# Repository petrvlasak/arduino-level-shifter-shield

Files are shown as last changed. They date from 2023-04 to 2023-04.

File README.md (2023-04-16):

# Arduino Logic Level Shifter Shield

This shield is used to convert the logic 1 (HIGH) voltage at the Arduino digital pins so that logic circuits that use a different logic 1 (HIGH) voltage can be connected to it. The Shield can be used with the Arduino UNO board and any other board that has the same layout and pinout as this board. The pins are divided into three groups of eight. It is possible to choose a different voltage for each of these three groups. In the third group, only four pins are connected to the Arduino. The remaining four pins S0 - S3 are of general use and convert the IOREF voltage to the voltage set for the third group. The voltage is changed by a switch that has three options:

1. Voltage 3.3 V from Arduino
2. The voltage set by the potentiometer on the regulator varies between approximately 1.5 V - 2.8 V (the input for the regulator can be pin +5V or pin Vin)
3. External voltage - The allowed range of this voltage is 1.4V - 3.6V

## Schematic

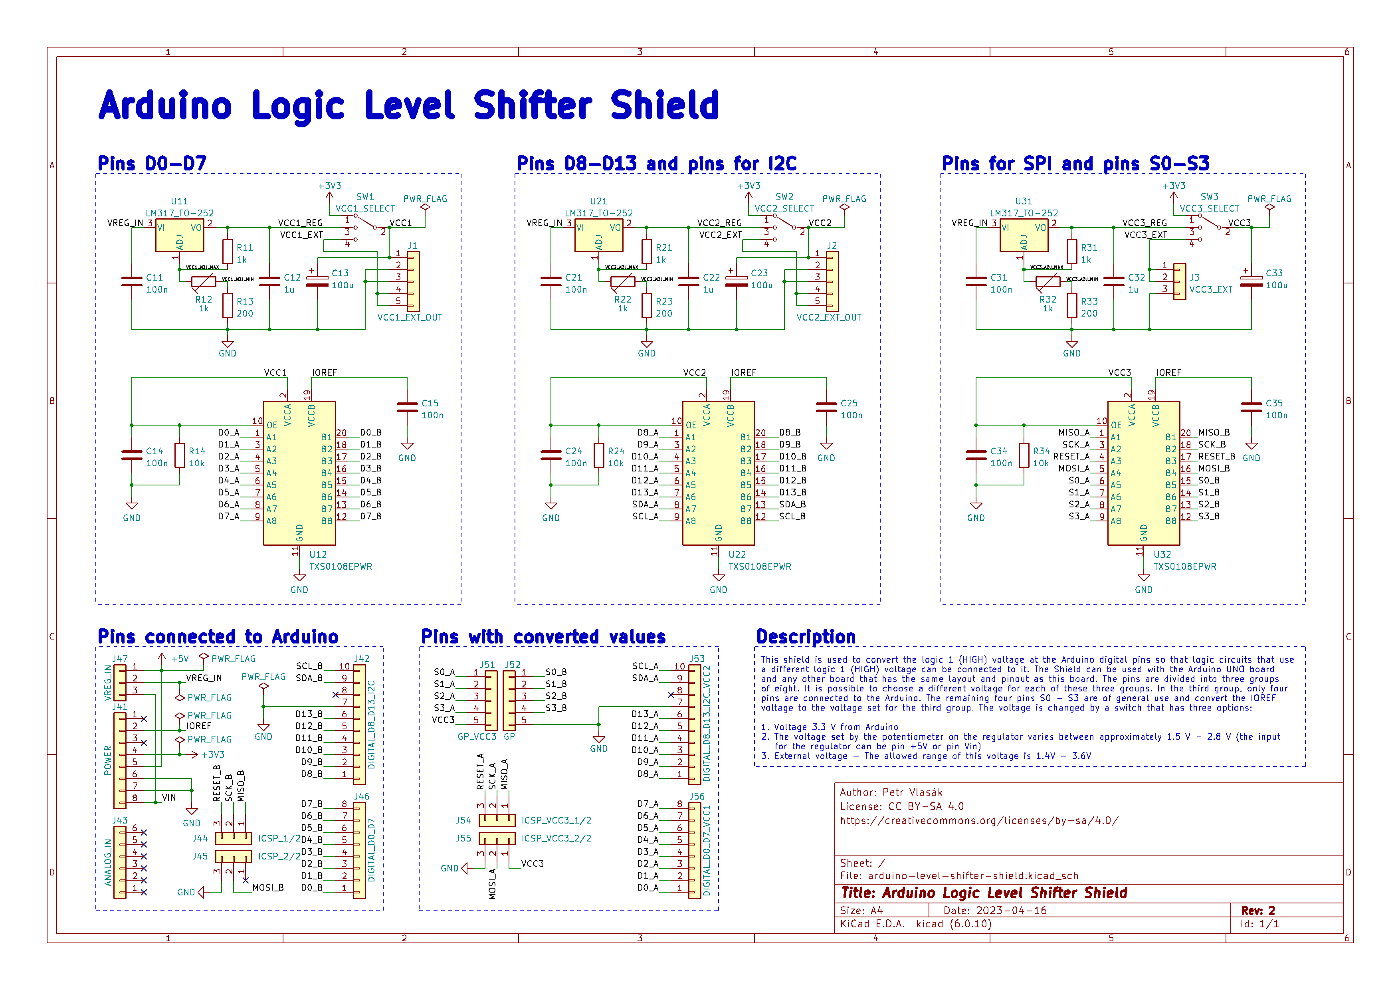
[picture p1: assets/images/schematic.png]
Schematic


## Manufacturing

The PCB manufacturing files are located [here](/manufacturing/).

## Placement plan

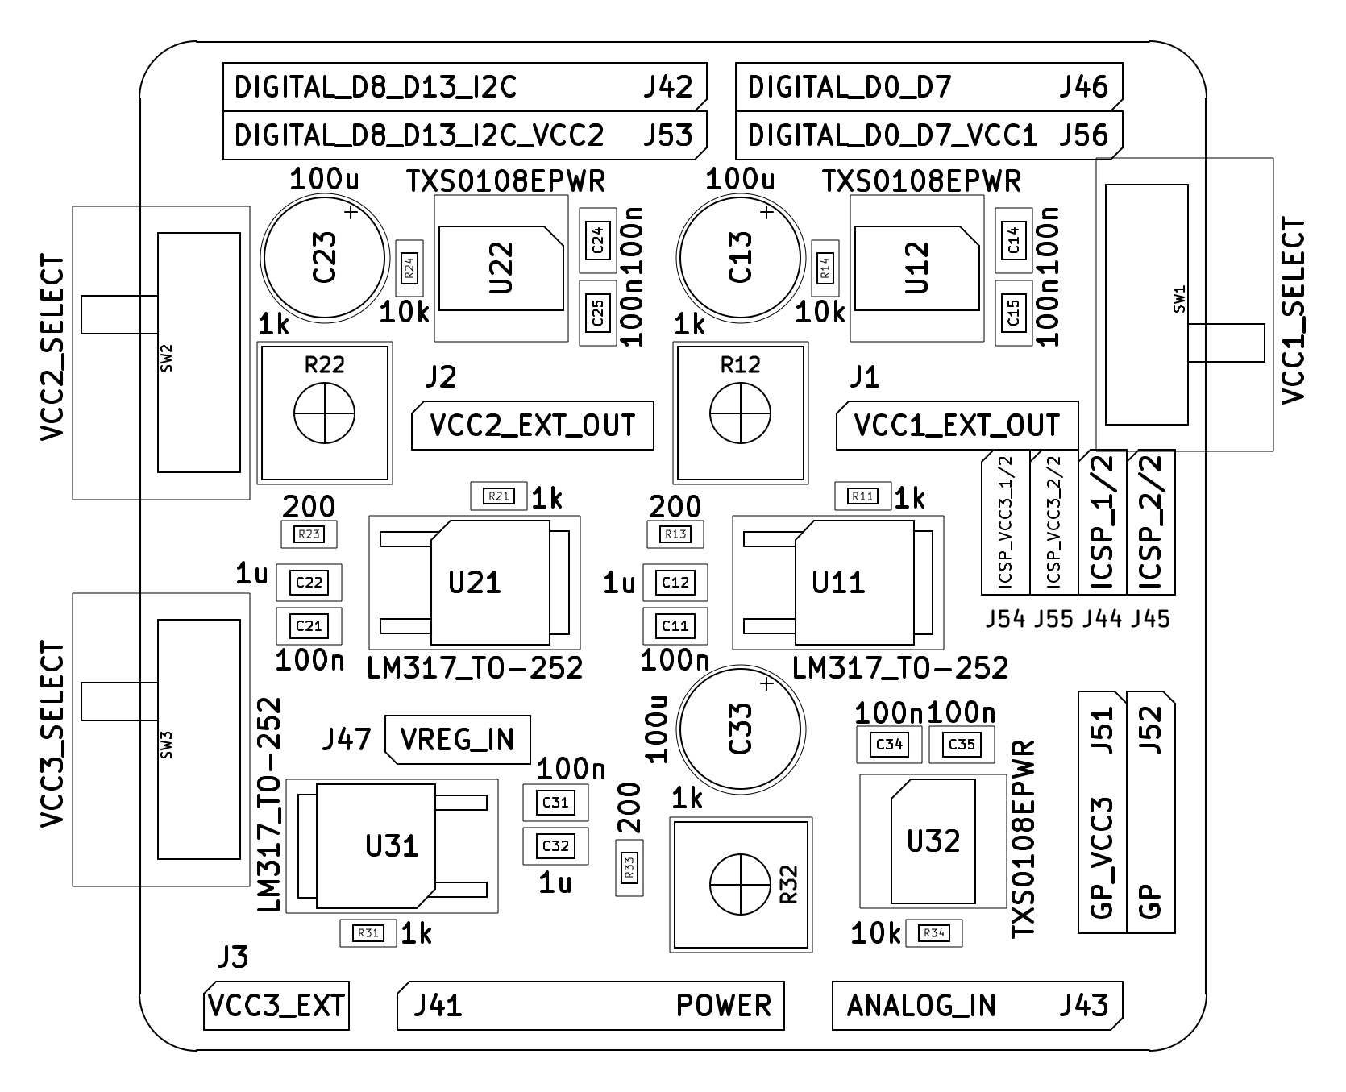
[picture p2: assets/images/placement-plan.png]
Placement plan


## Bill of materials

| Reference | Quantity | Value | Description |
| --- | --- | --- | --- |
| C11, C14, C15, C21, C24, C25, C31, C34, C35 | 9 | 100n | Capacitor SMD 0805 |
| C12, C22, C32 | 3 | 1u | Capacitor SMD 0805 |
| C13, C23, C33 | 3 | 100u | Capacitor THT Radial D6.3mm P2.50mm |
| R11, R21, R31 | 3 | 1k | Resistor SMD 0603 |
| R12, R22, R32 | 3 | 1k | Potentiometer Bourns 3362P Vertical |
| R13, R23, R33 | 3 | 200 | Resistor SMD 0603 |
| R14, R24, R34 | 3 | 10k | Resistor SMD 0603 |
| U11, U21, U31 | 3 |  | LM317 TO-252 |
| U12, U22, U32 | 3 |  | TXS0108EPW |
| SW1, SW2, SW3 | 3 |  | OS103011MA7QP1 |
| J47, J54, J55 | 3 |  | Pin Header 1x3 2.54mm |
| J3 | 1 |  | Pin Socket 1x3 2.54mm |
| J1, J2, J51, J52 | 4 |  | Pin Socket 1x5 2.54mm |
| J56 | 1 |  | Pin Socket 1x8 2.54mm |
| J53 | 1 |  | Pin Socket 1x10 2.54mm |

Components J41, J42, J43, J44, J45 and J46 are special pin headers for Arduino shields. I found two ways to buy them:

1. From SparkFun: 1 x [Arduino Stackable Header Kit - R3](https://www.sparkfun.com/products/11417) and 2 x [Stackable Header - 3 Pin (Female, 0.1")](https://www.sparkfun.com/products/13875)
2. From Adafruit: 1 x [Shield stacking headers for Arduino (R3 Compatible)](https://www.adafruit.com/product/85)

And finally you need one Mini Jumper 1x2 2.54mm to configure the input for the regulators (+5V or Vin).

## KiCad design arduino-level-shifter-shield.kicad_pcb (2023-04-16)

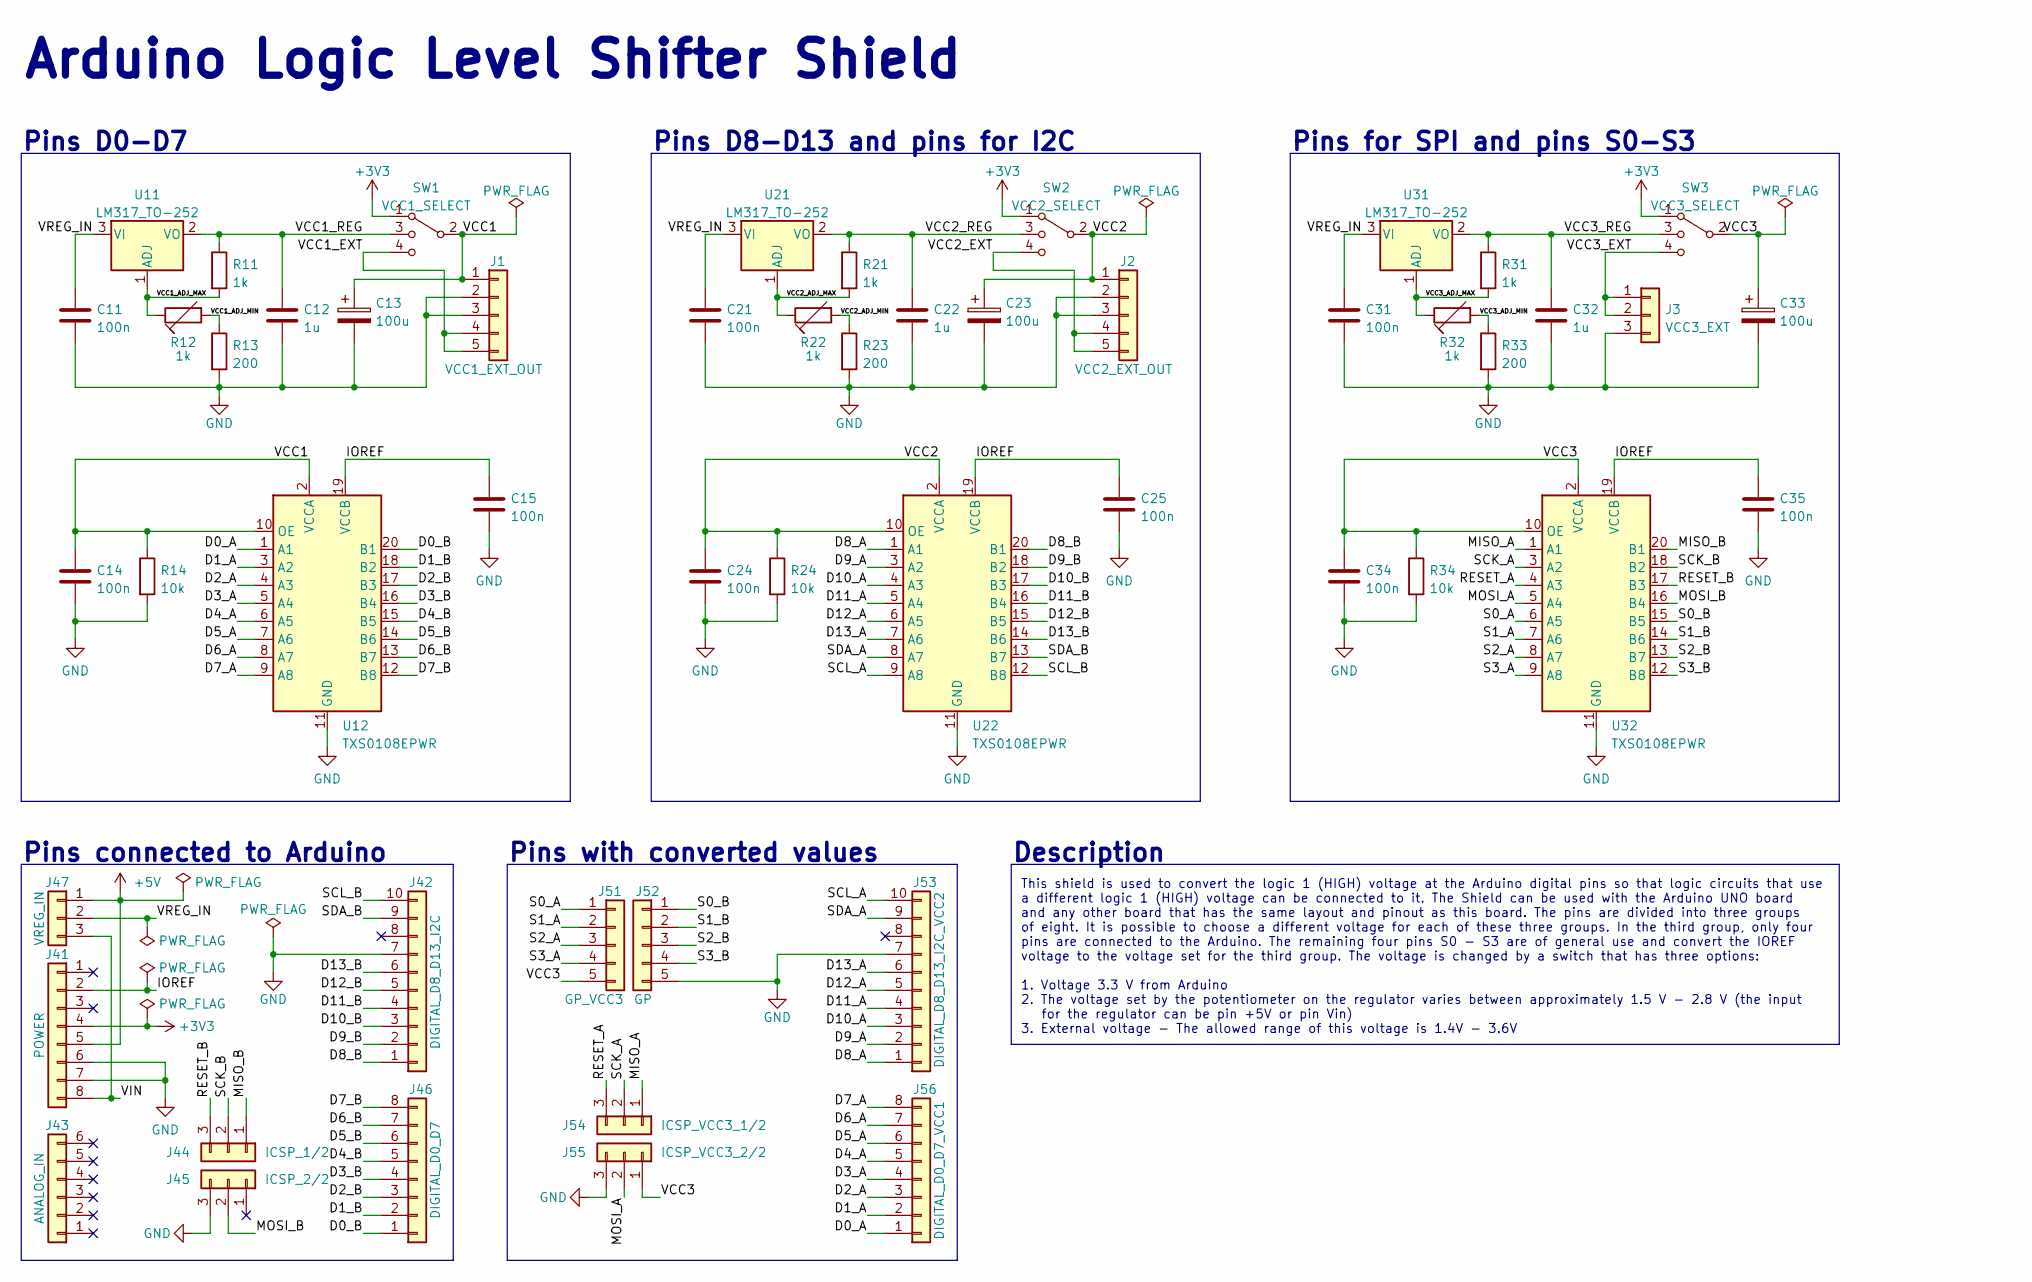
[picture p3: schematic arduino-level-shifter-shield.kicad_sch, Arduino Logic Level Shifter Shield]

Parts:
C11, C14, C15, C21, C24, C25, C31, C34, C35: 100n; C_0805_2012Metric
C12, C22, C32: 1u; C_0805_2012Metric
C13, C23, C33: 100u; CP_Radial_D6.3mm_P2.50mm
J1: VCC1_EXT_OUT; PinSocket_1x05
J2: VCC2_EXT_OUT; PinSocket_1x05
J3: VCC3_EXT; PinSocket_1x03
J41: POWER; PinSocket_1x08_long_legs
J42: DIGITAL_D8_D13_I2C; PinSocket_1x10_long_legs
J43: ANALOG_IN; PinSocket_1x06_long_legs
J44: ICSP_1/2; PinSocket_1x03_long_legs
J45: ICSP_2/2; PinSocket_1x03_long_legs
J46: DIGITAL_D0_D7; PinSocket_1x08_long_legs
J47: VREG_IN; PinHeader_1x03
J51: GP_VCC3; PinSocket_1x05
J52: GP; PinSocket_1x05
J53: DIGITAL_D8_D13_I2C_VCC2; PinSocket_1x10
J54: ICSP_VCC3_1/2; PinHeader_1x03
J55: ICSP_VCC3_2/2; PinHeader_1x03
J56: DIGITAL_D0_D7_VCC1; PinSocket_1x08
R11, R21, R31: 1k; R_0603_1608Metric
R12, R22, R32: 1k; Potentiometer_Bourns_3362P_Vertical
R13, R23, R33: 200; R_0603_1608Metric
R14, R24, R34: 10k; R_0603_1608Metric
SW1: VCC1_SELECT; SW_CuK_OS103011MA7QP1_SP3T_Angled
SW2: VCC2_SELECT; SW_CuK_OS103011MA7QP1_SP3T_Angled
SW3: VCC3_SELECT; SW_CuK_OS103011MA7QP1_SP3T_Angled
U11, U21, U31: LM317_TO-252; TO-252-2
U12, U22, U32: TXS0108EPWR; TSSOP-20_4.4x6.5mm_P0.65mm

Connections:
+3V3: J41.4, SW1.1, SW2.1, SW3.1
+5V: J41.5, J47.1
/D0_A: J56.1, U12.1 (A1)
/D0_B: J46.1, U12.20 (B1)
/D1_A: J56.2, U12.3 (A2)
/D1_B: J46.2, U12.18 (B2)
/D2_A: J56.3, U12.4 (A3)
/D2_B: J46.3, U12.17 (B3)
/D3_A: J56.4, U12.5 (A4)
/D3_B: J46.4, U12.16 (B4)
/D4_A: J56.5, U12.6 (A5)
/D4_B: J46.5, U12.15 (B5)
/D5_A: J56.6, U12.7 (A6)
/D5_B: J46.6, U12.14 (B6)
/D6_A: J56.7, U12.8 (A7)
/D6_B: J46.7, U12.13 (B7)
/D7_A: J56.8, U12.9 (A8)
/D7_B: J46.8, U12.12 (B8)
/D8_A: J53.1, U22.1 (A1)
/D8_B: J42.1, U22.20 (B1)
/D9_A: J53.2, U22.3 (A2)
/D9_B: J42.2, U22.18 (B2)
/D10_A: J53.3, U22.4 (A3)
/D10_B: J42.3, U22.17 (B3)
/D11_A: J53.4, U22.5 (A4)
/D11_B: J42.4, U22.16 (B4)
/D12_A: J53.5, U22.6 (A5)
/D12_B: J42.5, U22.15 (B5)
/D13_A: J53.6, U22.7 (A6)
/D13_B: J42.6, U22.14 (B6)
/IOREF: C15.1, C25.1, C35.1, J41.2, U12.19 (VCCB), U22.19 (VCCB), U32.19 (VCCB)
/MISO_A: J54.1, U32.1 (A1)
/MISO_B: J44.1, U32.20 (B1)
/MOSI_A: J55.2, U32.5 (A4)
/MOSI_B: J45.2, U32.16 (B4)
/RESET_A: J54.3, U32.4 (A3)
/RESET_B: J44.3, U32.17 (B3)
/S0_A: J51.1, U32.6 (A5)
/S0_B: J52.1, U32.15 (B5)
/S1_A: J51.2, U32.7 (A6)
/S1_B: J52.2, U32.14 (B6)
/S2_A: J51.3, U32.8 (A7)
/S2_B: J52.3, U32.13 (B7)
/S3_A: J51.4, U32.9 (A8)
/S3_B: J52.4, U32.12 (B8)
/SCK_A: J54.2, U32.3 (A2)
/SCK_B: J44.2, U32.18 (B2)
/SCL_A: J53.10, U22.9 (A8)
/SCL_B: J42.10, U22.12 (B8)
/SDA_A: J53.9, U22.8 (A7)
/SDA_B: J42.9, U22.13 (B7)
/VCC1: C13.1, C14.1, J1.1, R14.1, SW1.2, U12.2 (VCCA), U12.10 (OE)
/VCC1_ADJ_MAX: R11.2, R12.1, U11.1 (ADJ)
/VCC1_ADJ_MIN: R12.2, R13.1
/VCC1_EXT: J1.4, J1.5, SW1.4
/VCC1_REG: C12.1, R11.1, SW1.3, U11.2 (VO)
/VCC2: C23.1, C24.1, J2.1, R24.1, SW2.2, U22.2 (VCCA), U22.10 (OE)
/VCC2_ADJ_MAX: R21.2, R22.1, U21.1 (ADJ)
/VCC2_ADJ_MIN: R22.2, R23.1
/VCC2_EXT: J2.4, J2.5, SW2.4
/VCC2_REG: C22.1, R21.1, SW2.3, U21.2 (VO)
/VCC3: C33.1, C34.1, J51.5, J55.1, R34.1, SW3.2, U32.2 (VCCA), U32.10 (OE)
/VCC3_ADJ_MAX: R31.2, R32.1, U31.1 (ADJ)
/VCC3_ADJ_MIN: R32.2, R33.1
/VCC3_EXT: J3.1, J3.2, SW3.4
/VCC3_REG: C32.1, R31.1, SW3.3, U31.2 (VO)
/VIN: J41.8, J47.3
/VREG_IN: C11.1, C21.1, C31.1, J47.2, U11.3 (VI), U21.3 (VI), U31.3 (VI)
GND: C11.2, C12.2, C13.2, C14.2, C15.2, C21.2, C22.2, C23.2, C24.2, C25.2, C31.2, C32.2, C33.2, C34.2, C35.2, J1.2, J1.3, J2.2, J2.3, J3.3, J41.6, J41.7, J42.7, J45.3, J52.5, J53.7, J55.3, R13.2, R14.2, R23.2, R24.2, R33.2, R34.2, U12.11 (GND), U22.11 (GND), U32.11 (GND)

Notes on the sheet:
Pins for SPI and pins S0-S3
Pins with converted values
Pins D8-D13 and pins for I2C
Pins D0-D7
Arduino Logic Level Shifter Shield
This shield is used to convert the logic 1 (HIGH) voltage at the Arduino digital pins so that logic circuits that use a different logic 1 (HIGH) voltage can be connected to it. The Shield can be used with the Arduino UNO board and any other board that has the same layout and pinout as this board. T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
Pins connected to Arduino
Description

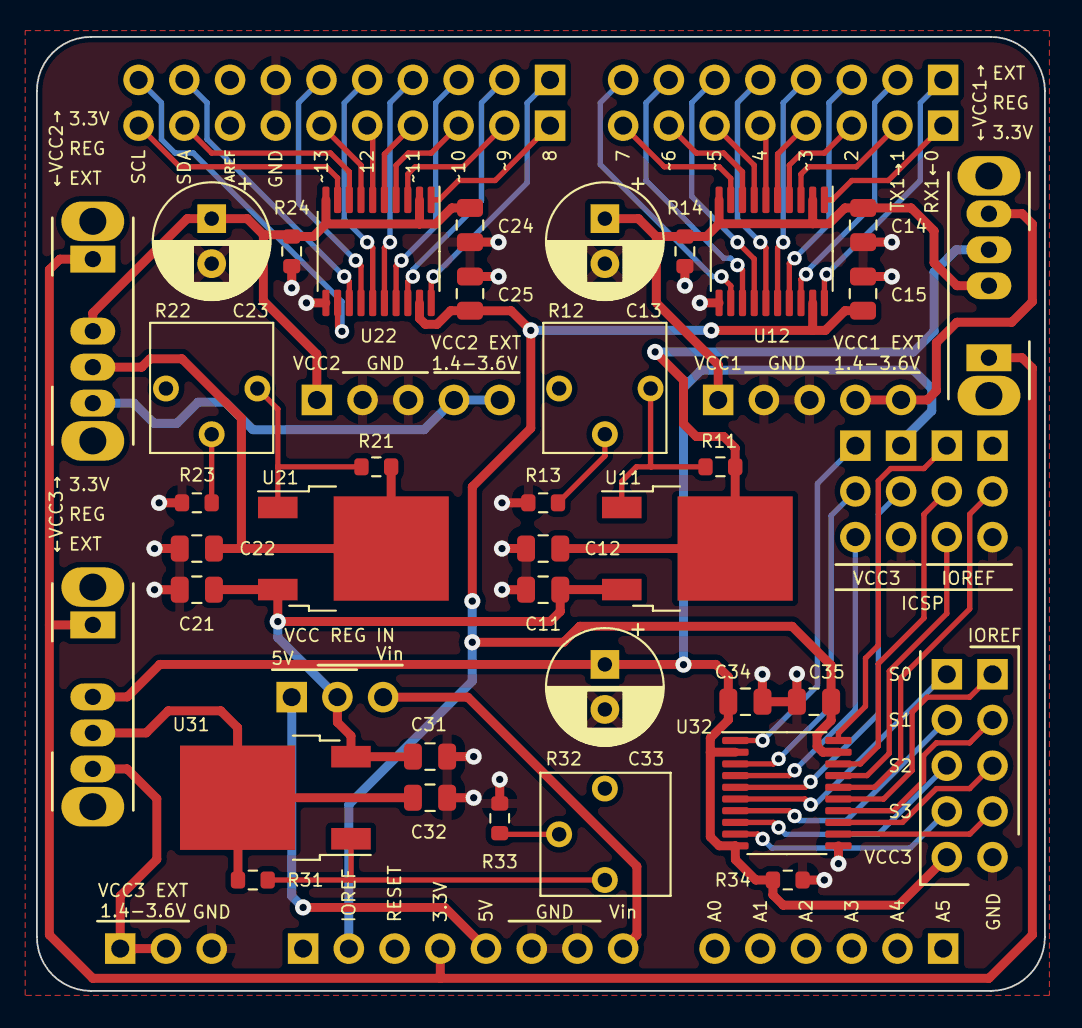
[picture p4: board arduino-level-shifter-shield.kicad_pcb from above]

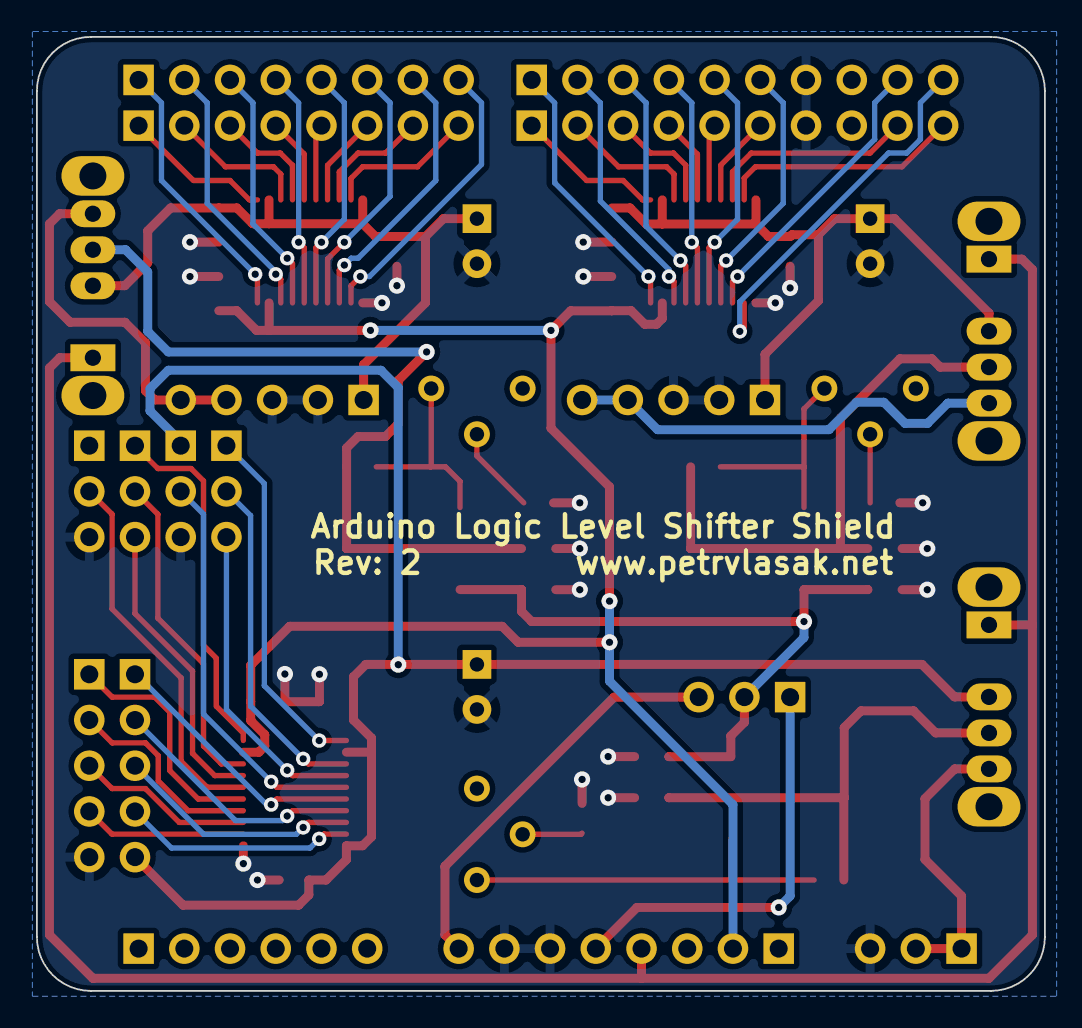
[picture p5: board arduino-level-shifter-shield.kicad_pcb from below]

Board: 2 copper layers, 56.0 x 53.0 mm, 52 parts (2 on the bottom side), 69 nets.

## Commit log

2023-03-20 Added license information
    [arduino-level-shifter-shield.kicad_pcb, arduino-level-shifter-shield.kicad_sch]
2023-04-16 Rev: 2
    [arduino-level-shifter-shield-B_Cu.gbr, arduino-level-shifter-shield-B_Mask.gbr, arduino-level-shifter-shield-B_Paste.gbr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]

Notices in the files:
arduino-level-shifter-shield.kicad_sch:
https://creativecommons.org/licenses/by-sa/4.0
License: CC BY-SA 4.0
